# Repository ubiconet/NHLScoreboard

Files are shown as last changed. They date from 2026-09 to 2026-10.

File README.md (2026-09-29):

# NHLScoreboard

ESP32-S3 firmware for a mini NHL scoreboard — a port of the
[MLBScoreboard](https://github.com/ubiconet/mlb_scoreboard) template (same
hardware and framework; the sport layer now lives at `src/sports/nhl/` under
NHL naming). The data layer still speaks the template's MLB feeds; the NHL
rewrite against the documented NHL web API (`docs/features/nhl-api/`) is
the next step.

Hardware (full topology + pin map: [`docs/hardware.md`](docs/hardware.md);
assembly guide + wiring diagram + tables:
[`docs/assembly.md`](docs/assembly.md)):
2.0" ST7789 TFT (320×240) for game details, 3× MAX7219 8×8 matrices (home
score, guest score, period), a TM1637 4-digit period clock, a MAX98357 I2S
audio amp for the goal horn, and 4 penalty LEDs (2 home, 2 guest). Live
linescore for your preferred teams, upcoming-game countdowns, a league news
ticker, an over-the-air captive-portal setup page, and GitHub-hosted
firmware self-update.

The repo is also a **sport scoreboard template**: the generic framework
(`src/common/` + `src/main.cpp`) is sport-agnostic, and everything NHL
lives in `src/sports/nhl/`. See *Starting a new sport* below.

## Architecture

```
┌─────────────────────────── core 1 (Arduino loop) ──────────────────────┐
│ main.cpp (generic shell)      sports/nhl/nhl_app.cpp + renderers       │
│  boot / OTA screen /          WAITING↔LIVE state machine,             │
│  boot status / NTP sync  ──▶  linescore, carousel, news ticker        │
│                               │ takes POD snapshots                   │
└───────────────────────────────┼────────────────────────────────────────┘
                                │ SnapshotChannel<T> (lock-free, gen ctr)
┌────────────────────────── core 0 (FreeRTOS) ───────────────────────────┐
│ network_service (Wi-Fi AP/portal, P2)   nhl_data_task (feeds, P1)     │
│ ota_update (self-update via TLS)         nhl_client → http_fetch      │
└────────────────────────────────────────────────────────────────────────┘
```

Source layout and conventions: see `AGENTS.md` §1. Build/deploy: `AGENTS.md`
§2. Released binaries + `manifest.json` live in [`releases/`](releases/) —
devices self-update from them after boot.

## Building

```powershell
& 'C:\Users\Steve\.platformio\penv\Scripts\platformio.exe' run --environment esp32-s3-devkitc-1
```

Hardware notes (pins, the software-SPI gotcha, heap/TLS constraints) are in
`docs/` and `AGENTS.md`. The verified NHL API reference (endpoints, payload
sizes, TLS constraints) lives in
[`docs/features/nhl-api/README.md`](docs/features/nhl-api/README.md).

## Starting a new sport from this template

The framework (`src/main.cpp` + `src/common/`) never names a sport. A sport
is a folder under `src/sports/` that implements the `sport::` contract
(`src/common/app/sport_api.h`) and provides `sport_config.h`. Checklist:

1. **Copy the repo** (new GitHub repo per sport keeps OTA streams separate).
2. **Copy `src/sports/nhl` → `src/sports/<sport>`** and rewrite the sport:
   - `sport_config.h` — pins/panel geometry, branding (AP SSID, hostname,
     portal title), UI theme colors, feed poll cadences.
   - `nhl_teams.*` — the league's team table `{id, abbrev, label}`.
   - `nhl_snapshot.h` — your live-game POD structs (the MLB template's
     carries balls/strikes/outs and base runners; hockey carries period,
     shots, power play…).
   - `nhl_client.*` — feed endpoints + JSON filters (build on
     `common/comms/http_fetcher`; keep payloads small and check the
     league's transport — the NHL API is HTTPS-only, see
     `docs/features/nhl-api/README.md`).
   - `nhl_data_task.cpp` — poll cadence + parse-to-snapshot publishing.
     **Keep the OTA wiring**: the loop must call
     `serviceOtaUpdates(onlineFor)` every pass, hold feeds while
     `otaUpdateInProgress()`, and gate the first feed fetch behind
     `otaBootGateReached()` — the NHL port dropped these calls once and
     the GitHub self-updater was silently dead until v3.19.
   - `nhl_app.cpp` / renderer files — your screens and state machine.
   - `team_logos.h` / `boot_logo.h` — regenerate assets
     (`tools/gen_boot_logo.py` pattern: RGB565, 0x1909 transparent).
3. **Point the env at it** in `platformio.ini`: change `+<sports/nhl/>`
   to `+<sports/<sport>/>` in `build_src_filter` and `-Isrc/sports/nhl`
   to `-Isrc/sports/<sport>` in `build_flags`, then delete the old folder.
4. **Repo identity**: set `OTA_MANIFEST_URL` / `OTA_LATEST_BIN_URL` in
   `src/config.h`, and `RAW_BASE` + `LATEST_FILE` in
   `tools/release_deploy.py`, to the new repo; bump `FIRMWARE_VERSION` to
   `v1.0`.
5. Build, USB-flash, walk through the setup portal, and run a live-game
   session against your feed.

Notes for the port: NVS keys (`ssid`, `team1..3`, `show_clock`) are shared
by design so a re-purposed board keeps its Wi-Fi; team ids are league-local,
so clear/re-pick teams in the portal after re-flashing a board.

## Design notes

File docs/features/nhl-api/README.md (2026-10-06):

# NHL API — primary data source (verified reference)

The NHL publishes **no official API documentation**. What follows was verified
live against production endpoints on **2026-09-24** (preseason week of the
2026-27 season). The NHL runs two public, unauthenticated surfaces:

| Surface | Base URL | Role for this project |
|---|---|---|
| **Web API** (powers nhl.com) | `https://api-web.nhle.com/v1/` | **Primary**: schedule, live scores, game detail, standings |
| **Stats REST** | `https://api.nhle.com/stats/rest/en/…` | Secondary: team directory (source for the team table) |

Community references (kept up to date by reverse engineering):
<https://github.com/dword4/nhlapi> and the unofficial NHL API reference
mirrors linked from it. The old `statsapi.web.nhl.com/api/v1` API is **dead**
(dark since ~2023); any guide referencing it is out of date.

## Transport properties (all verified)

- **HTTPS only.** `http://` answers `301` (Cloudflare) to the `https://` URL.
  This is a major departure from the MLB template, which ran feeds over plain
  HTTP and reserved TLS for OTA only — see *ESP32 constraints* below.
- **No authentication**, no API key, no required headers (works with a bare
  `curl` User-Agent).
- **No response filtering.** Unlike MLB's `?fields=` parameter there is no way
  to slim a payload server-side; sizes below are full bodies.
- HTTP/1.1 **keep-alive** works; served via Cloudflare with
  `Cache-Control: max-age=14` and a weak ETag — polling a live endpoint faster
  than ~15 s mostly hits CDN cache.
- Localized string fields are objects: `{"default": "Penguins", "fr": …}` —
  always read the `default` sub-key.
- `/v1/*/now` endpoints answer **307 redirects** to the current date. On the
  device, compute the date locally from the NTP-synced clock instead of
  following redirects (a redirect doubles the TLS round trips).

## Game identity & state

- **Game id** (e.g. `2026010016`): `YYYY` + 2-digit `gameType` + 4-digit
  sequence. `gameType`: `1` preseason, `2` regular season, `3` playoffs.
  The `season` field is the two years joined: `20262027`.
- **`gameState`** (observed: `FUT`, `FINAL`, `OFF`; community also documents
  `PREVIEW`, `LIVE`, `CRIT`):
  - `FUT` — scheduled, future
  - `PREVIEW` — game day, before start
  - `LIVE` — in progress
  - `CRIT` — critical/late (final minutes, OT)
  - `FINAL` / `OFF` — completed (`OFF` = official/finalized)
- **`periodDescriptor`**: `{"number": 3, "periodType": "REG", "maxRegulationPeriods": 3}`
  — `periodType` is `REG`, `OT`, or `SO` (shootout).

## Endpoints

### `GET /v1/score/{yyyy-mm-dd}` — day scoreboard *(waiting-mode poll)*

~42 KB. Top-level: `prevDate`, `currentDate`, `nextDate`, `gameWeek[]`
(per-day `date`/`dayAbbrev`/`numberOfGames` metadata only), `games[]`.

Each game carries the live essentials in one flat array (this is the smallest
"everything happening today" payload):

```json
{"id": 2026010016, "season": 20262027, "gameType": 1,
 "gameDate": "2026-09-21", "startTimeUTC": "2026-09-21T23:00:00Z",
 "gameState": "FINAL", "gameScheduleState": "OK",
 "clock": {"timeRemaining": "00:00", "secondsRemaining": 0,
           "running": false, "inIntermission": false},
 "period": 3, "periodDescriptor": {"number": 3, "periodType": "REG",
                                   "maxRegulationPeriods": 3},
 "gameOutcome": {"lastPeriodType": "REG"},
 "awayTeam": {"id": 7, "name": {"default": "Sabres"}, "abbrev": "BUF",
              "score": 1, "sog": 24,
              "logo": "https://assets.nhle.com/logos/nhl/svg/BUF_light.svg"},
 "homeTeam": {"id": 5, "name": {"default": "Penguins"}, "abbrev": "PIT",
              "score": 4, "sog": 28, "logo": "..."},
 "goals": [ … ], "tvBroadcasts": [ … ], "venue": {"default": "PPG Paints Arena"},
 "gameCenterLink": "/gamecenter/pit-vs-buf/2026/09/21/2026010016"}
```

One request covers every game of the day — the analog of the MLB template's
single schedule fetch.

### `GET /v1/schedule/{yyyy-mm-dd}` — week schedule *(schedule cache / countdown)*

~85 KB. Returns the **Mon–Sun week containing the date**, plus:
`nextStartDate` / `previousStartDate` (for paging), `numberOfGames`, and the
season boundaries `preSeasonStartDate`, `regularSeasonStartDate`,
`regularSeasonEndDate`, `playoffEndDate` (useful for "is today in season").

Game objects here add vs. `/v1/score`: `commonName`/`placeName` (split team
names), `darkLogo`, `winningGoalie`, `winningGoalScorer`, `threeMinRecap`,
`condensedGame`, `oddsPartners`.

### `GET /v1/gamecenter/{id}/landing` — live game summary *(live-screen poll)*

~11 KB. **The NHL analog of MLB's `/linescore`** — poll this while a followed
game is live:

```json
{"id": 2025020001, "gameState": "OFF",
 "periodDescriptor": {"number": 3, "periodType": "REG"},
 "clock": {"timeRemaining": "00:00", "secondsRemaining": 0,
           "running": false, "inIntermission": false},
 "shootoutInUse": false, "otInUse": true, "tiesInUse": false,
 "maxPeriods": 5, "regPeriods": 3,
 "homeTeam": {"abbrev": "FLA", "score": 3, "sog": 37, …},
 "awayTeam": {"abbrev": "CHI", "score": 2, "sog": 19, …},
 "summary": {
   "scoring": [
     {"periodDescriptor": {"number": 1}, "goals": [
        {"strength": "ev", "playerId": 8483493, "name": {"default": "F. Nazar"},
         "teamAbbrev": {"default": "CHI"}, "situationCode": "1551",
         "highlightClipSharingUrl": "https://nhl.com/vid…"}]},
     … one entry per period with goals …],
   "threeStars": [ {"star": 1, "name": {"default": "…"}, "teamAbbrev": "FLA",
                    "goals": 1, "assists": 0, "points": 1} ],
   "penalties": [ {"periodDescriptor": {"number": 1}, "penalties": [
        {"timeInPeriod": "06:58", "duration": 2, "descKey": "slashing",
         "teamAbbrev": {"default": "CHI"}}]}]}}
```

A period-by-period **linescore is derived** from `summary.scoring[]` (count
`goals[]` per `teamAbbrev` per period). Shots on goal per period are **not**
exposed here — only game totals (`sog`); per-period shots must be aggregated
from play-by-play if a screen ever needs them.

The live scoreboard also filters each scoring entry's scorer and assist
names, IDs, and sweater numbers from this summary. If the scorer's sweater
number is absent, it makes a one-time, roster-only filtered
`/v1/gamecenter/{id}/play-by-play` request when the score first increases;
the large play/event list is not retained or fetched on routine polls.
The same pass counts goals per `teamAbbrev` per period group (the group's
`periodDescriptor` is part of the filter) to build the per-period
linescore strip, and `summary.threeStars[]` (name, sweater number, team,
G/A) feeds the postgame three-stars screen — that array is only populated
at or near game end.

`situationCode` encodes strength as four digits —
`[awayGoalies][awaySkaters][homeSkaters][homeGoalies]`, e.g. `"1551"` = 5v5
with both goalies, `"0651"` = away team on an empty-net extra attacker. This
is the natural source for a **power-play indicator** (replacing MLB's
balls/strikes/outs LEDs — actual LED meaning is a board-topology decision,
out of scope here).

### `GET /v1/gamecenter/{id}/boxscore` — box score

~13.5 KB. Same envelope (`gameState`, `clock`, `periodDescriptor`, teams with
`score` + `sog`) plus `playerByGameStats: {homeTeam/awayTeam:
{forwards, defense, goalies}}` (per-player G/A/TOI/SOG…) and `gameOutcome`.
Use for a stats screen; **not** needed for the live poll.

### `GET /v1/gamecenter/{id}/play-by-play` — full event stream

~146 KB for a completed regular-season game. `plays[]` (361 events in the
sample): `eventId`, `periodDescriptor`, `timeInPeriod`, `timeRemaining`,
`situationCode`, `typeCode`/`typeDescKey` (`period-start`, `faceoff`,
`shot-on-goal`, `goal`, `stoppage`, `game-end`, …), event `details` (players,
zone, coordinates), `sortOrder`; plus `rosterSpots` and a `summary`.
The last `plays[]` entry is the "current play" analog of MLB's live feed.

Too large for the render path and marginal for the ESP32 parse budget —
reserve for an on-demand drill-down screen, parsed on core 0 with a streaming
filter (see constraints).

### `GET /v1/standings/{yyyy-mm-dd}` — standings

~60 KB. `/v1/standings/now` 307-redirects to the latest date with standings —
during the 2026 preseason that was **2026-04-17** (end of the previous
season), which is the right behavior for an offseason carousel. Entries
include `divisionAbbrev`/`conferenceAbbrev` + rank sequences,
`wildCardIndicator`, `clinchIndicator`, `gamesPlayed`, `points`, `pointPctg`,
`goalDifferential`, L10/home/road splits.

### `GET https://api.nhle.com/stats/rest/en/team` — team directory

~6.7 KB: `{"data": [{"id": 32, "franchiseId": 27, "fullName": "Quebec
Nordiques", "leagueId": 133, "rawTricode": "QUE", "triCode": "QUE"}, …]}`.
**Includes defunct franchises** — filter to the 32 active clubs when
generating the hardcoded `nhl_teams.*` table (`{id, abbrev, label}`). Supports
`cayenne_exp` filter expressions (community-documented); the scoreboard
itself never needs them.

### Team logos & player assets

Embedded in schedule/score payloads:
- `https://assets.nhle.com/logos/nhl/svg/{ABBREV}_light.svg`
- `https://assets.nhle.com/logos/nhl/svg/{ABBREV}_dark.svg`
  (some carry `?season=YYYYYYYY`)
- Player headshots: `https://assets.nhle.com/mugs/nhl/{season}/{ABBREV}/{playerId}.png`

### News

**No accessible official NHL endpoint**: `/v1/news` → 404, and
`https://www.nhl.com/rss/news.xml` → 403 (Akamai bot filter — would likely
block the ESP32 too). Chosen source (live since v1.8): **ESPN's NHL feed on
`site.api.espn.com`** over plain HTTP —
`http://site.api.espn.com/apis/site/v2/sports/hockey/nhl/news?limit=10`
(~27 KB with limit=5; `articles[].headline`/`description` are all the
ticker parses, via a streaming filter). ESPN's `www.espn.com/espn/rss/nhl/news`
RSS carries the same stories at 9 KB but **301-forces HTTPS**, which the
TLS-free feed architecture (see `common/comms/http_fetcher.h`) avoids; the
api host serves plain HTTP with no redirect and tolerated an ESP32
User-Agent in testing. Keep the ≥30-min cache rule and the gentle retry
pacing (`NHL_NEWS_RETRY_MS`) — ESPN's edge has a temper.

## MLB template → NHL mapping (porting cheat sheet)

| MLB template | NHL equivalent |
|---|---|
| `gamePk` | `id` (`2026010016`) |
| `/api/v1/schedule?sportId=1&date=` | `/v1/score/{date}` (day, 42 KB) or `/v1/schedule/{date}` (week, 85 KB) |
| `/game/{pk}/linescore` | `/v1/gamecenter/{id}/landing` (11 KB) |
| `/game/{pk}/boxscore` | `/v1/gamecenter/{id}/boxscore` (13.5 KB) |
| `/v1.1/game/{pk}/feed/live` | `/v1/gamecenter/{id}/play-by-play` (146 KB) |
| `/api/v1/standings` | `/v1/standings/{date}` |
| `detailedState` (PreGame/InPlay/Over) | `gameState` (PREVIEW/LIVE·CRIT/FINAL·OFF) |
| inning / half inning | `periodDescriptor.number` + `periodType` (REG/OT/SO) |
| inning-by-inning runs | derive from `landing.summary.scoring[]` |
| at-bat | last `plays[]` entry / `situationCode` strength |
| balls/strikes/outs | power-play/strength indicator (board topology TBD) |
| `team.id` / `abbrev` / name | `id` / `abbrev` / `placeName` + `commonName` |
| W-L record in standings | `points`, `pointPctg`, wildcard flags |
| ESPN `mlb` news | ESPN `hockey/nhl` news |

## ESP32 constraints (architecture notes for the rewrite)

- **Everything is TLS now.** The MLB template ran feeds on plain HTTP with a
  single reused TLS session reserved for OTA. With NHL feeds, every fetch is
  TLS: plan on one reused `WiFiClientSecure` connection per poll cycle on
  core 0, never concurrent sessions (the OTA rule "no second TLS connection
  while one is alive" still applies and now interacts with feed polling —
  the feed session must close before the OTA updater runs, as the template
  already does via `http_fetch::closeSession()`).
- **Payload budget.** `score` (42 KB), `landing` (11 KB) and `boxscore`
  (13.5 KB) fit the template's buffered-parse discipline. `schedule` week
  (85 KB), `standings` (60 KB) and especially `play-by-play` (146 KB) must
  be fetched sparsely (schedule cache / carousel TTL) or parsed with a
  streaming filter on core 0 — never parsed on the render core.
- **No `fields=` filtering** — filter in the parser.
- **CDN freshness is 14 s** — a 15–20 s live cadence is the fastest useful
  poll; faster requests just hit Cloudflare cache.
- **Avoid `/now`** — compute dates locally (NTP) rather than following 307s.
- Localized fields are objects — always read `.default`.

## Samples (captured 2026-09-24)

| File | Endpoint | Size |
|---|---|---|
| `samples/score-2026-09-21.json` | `/v1/score/2026-09-21` | 42 KB |
| `samples/schedule-2026-09-21.json` | `/v1/schedule/2026-09-21` | 85 KB |
| `samples/landing-2025020001.json` | `/v1/gamecenter/2025020001/landing` | 11 KB |
| `samples/boxscore-2025020001.json` | `/v1/gamecenter/2025020001/boxscore` | 13.5 KB |
| `samples/play-by-play-2025020001.json` | `/v1/gamecenter/2025020001/play-by-play` | 146 KB |

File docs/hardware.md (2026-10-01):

# Hardware — NHL board topology & physical pin map

The NHL build's outputs, their drivers, and the GPIO plan mapped to the
**physical header positions** of the actual dev board (the logical GPIO
numbers are NOT in order on its headers, so assignments below are chosen
for physical sequence). **v3.44 moved the TFT and the guest penalty LEDs
to the backplane-PCB routing** (`pcb.md`) — the dev-board headers below
are now intermediate, but the GPIO↔position map is still the board's
truth. Since v2.0 the firmware drives this target map for the TM1637,
penalty LEDs, and the MAX7219 chain; the remaining topography items are
the third (period) MAX7219 module — the `led_matrix` HAL still drives
two — and the MAX98357 I2S audio output.

For building the physical board see **[`assembly.md`](assembly.md)** —
parts list, wiring tables, the rendered wiring diagram
(`wiring-diagram.png`), and the first-boot checklist.

## Board

ESP32-S3 DevKit ("esp32s1-devkit1", a YD-ESP32-S3-family 44-pin DevKitC-1
clone), **ESP32-S3-WROOM-1 N8R8** (8 MB quad flash + 8 MB octal PSRAM).
Two USB-C ports at the bottom edge: the **native USB OTG** port (GPIO
19/20 — use this one for `Serial`/CDC and flashing) and a **USB-UART
bridge** port (CH343 → GPIO 43/44). RST + BOOT buttons on the side, and an
onboard WS2812 RGB LED on **GPIO48** (don't use 48 for I/O). On some YD
boards the `USB-OTG` solder jumper ships open — close it if the native USB
port is dead. Both headers below are confirmed against the board (note:
position 7 on the right is GPIO41 — easy to misread as 21, but 21 sits at
position 18 and a GPIO can't appear twice).

## Outputs

| # | Output | Part | Role | Interface | GPIOs |
|---|---|---|---|---|---|
| 1 | Home score | MAX7219 8×8 matrix | Home goals | chained SPI | 40/39/38 |
| 2 | Guest score | MAX7219 8×8 matrix | Guest goals | chained SPI | (same chain) |
| 3 | Period | MAX7219 8×8 matrix | 1–4, OT, SO | chained SPI | (same chain) |
| 4 | Period clock | TM1637 4-digit 7-seg | MM:SS game clock | 2-wire bit-bang | 16/17 |
| 5 | Audio | MAX98357 I2S amp + speaker | goal horn / cues | I2S | 1/2/42 |
| 6 | Home penalties | 2 discrete LEDs | penalty 1 / penalty 2 | GPIO direct | 4/5 |
| 7 | Guest penalties | 2 discrete LEDs | penalty 1 / penalty 2 | GPIO direct | 11/12 |
| 8 | Game details | 2.0" ST7789 240×320 TFT | linescore, carousel, portal | software SPI | 8/3/9/10/46 |

**Total: 17 GPIOs.** Wiring-friendly split: **left header = indicators +
displays**, **right header = serial buses** (audio + score matrices).

## Physical header map

### LEFT header (top → bottom, confirmed)

| Pos | Pin | Assigned to | Note |
|---|---|---|---|
| 1 | 3V3 | — | power for TM1637 |
| 2 | 3V3 | — | power for TFT |
| 3 | RST | — | |
| 4 | GPIO4 | Home penalty LED 1 | |
| 5 | GPIO5 | Home penalty LED 2 | |
| 6 | GPIO6 | — spare — | guest LED until the PCB rev (v3.44) |
| 7 | GPIO7 | — spare — | guest LED until the PCB rev (v3.44) |
| 8 | GPIO15 | — gap — | spare |
| 9 | GPIO16 | TM1637 CLK | |
| 10 | GPIO17 | TM1637 DIO | |
| 11 | GPIO18 | — gap — | spare |
| 12 | GPIO8 | TFT SCL (SCK) | PCB rev v3.44 |
| 13 | GPIO3 | TFT SDA (MOSI) | strapping pin (JTAG source) — output OK after boot |
| 14 | GPIO46 | TFT RESET | strapping pin — output OK after boot; reset state only gates ROM log |
| 15 | GPIO9 | TFT DC | |
| 16 | GPIO10 | TFT CS | |
| 17 | GPIO11 | Guest penalty LED 1 | |
| 18 | GPIO12 | Guest penalty LED 2 | |
| 19 | GPIO13 | — spare — | PENALTY_FILL_A dummy (init'd, never lit) |
| 20 | GPIO14 | — gap — | spare |
| 21 | 5V | — | power for MAX7219 chain + MAX98357 |
| 22 | GND | — | |

### RIGHT header (top → bottom, confirmed)

| Pos | Pin | Assigned to | Note |
|---|---|---|---|
| 1 | GND | — | ground for I2S/matrices |
| 2 | TX (43) | — | UART debug spare |
| 3 | RX (44) | — | UART debug spare |
| 4 | GPIO1 | MAX98357 BCLK | |
| 5 | GPIO2 | MAX98357 LRC (WS) | |
| 6 | GPIO42 | MAX98357 DIN (data) | |
| 7 | GPIO41 | — gap — | spare (JTAG MTDO) |
| 8 | GPIO40 | MAX7219 DIN (chain in) | |
| 9 | GPIO39 | MAX7219 CLK | |
| 10 | GPIO38 | MAX7219 CS / LOAD | |
| 11 | GPIO37 | ✗ | octal PSRAM (N8R8) |
| 12 | GPIO36 | ✗ | octal PSRAM (N8R8) |
| 13 | GPIO35 | ✗ | octal PSRAM (N8R8) |
| 14 | GPIO0 | ✗ | strap / boot button |
| 15 | GPIO45 | ✗ | strapping pin |
| 16 | GPIO48 | ✗ | onboard RGB LED |
| 17 | GPIO47 | — spare — | expansion |
| 18 | GPIO21 | — spare — | expansion |
| 19 | GPIO20 | ✗ | native USB D+ |
| 20 | GPIO19 | ✗ | native USB D− |
| 21 | GND | — | |
| 22 | GND | — | |

## Design rationale

1. **Physical sequence per device.** Each peripheral occupies consecutive
   header positions: LEDs 4–7, TM1637 9–10, TFT 15–19 (left); I2S 4–6,
   MAX7219 chain 8–10 (right). One-position gaps (left 8, 11, 20; right 7)
   separate devices visually and electrically.
2. **Minimal pins.** The three MAX7219 matrices share one 3-pin daisy
   chain (CLK + CS common, data cascades DOUT→DIN), so the Period matrix
   costs zero extra pins. TM1637 is 2 pins, MAX98357 is 3 (I2S), penalty
   LEDs are 4.
3. **PCB routing wins (v3.44).** The original map put the TFT on the
   MLB-proven `CS=9, DC=10, RESET=11, MOSI=12, SCK=13` run (left 15–19)
   and the guest LEDs on 6/7; the backplane PCB's routing moved the TFT to
   `SCK=8, MOSI=3, CS=10, DC=9, RESET=46` and the guest LEDs to 11/12.
   GPIO 3 and 46 are strapping pins, but both are TFT inputs on the module
   side, so the strap sample at reset is undisturbed and both work fine
   as outputs once firmware drives them.
4. **Avoided by design:** GPIO 35–37 (octal PSRAM on N8R8), 0/45
   (straps), 48 (onboard RGB), 19/20 (native USB), 43/44 (debug UART).
   46 (strap) is now the TFT reset — tolerated because its reset-time
   state only gates ROM log output. When adding parts prefer GPIO 15/18/14
   (left) or 41/47/21 (right).

## Wiring notes

**MAX7219 chain** — data flows GPIO 40 → matrix 1 (Guest) DIN → DOUT →
matrix 2 (Period) DIN → DOUT → matrix 3 (Home) DIN. CLK and CS/LOAD are
shared by all three. With a shared LOAD the first bytes shifted land in
the **last** physical device (home) — the driver's `max7219Send3` orders
its slots accordingly.

**TM1637** — power from 3V3 (left pos 1/2): its input high threshold
scales with VCC, so 5 V power makes 3.3 V logic marginal. Slightly dimmer
at 3V3 but 100 % reliable.

**MAX98357** — Vin from 5V; logic inputs are 3.3 V safe. Leave SD
unconnected (default: active, 9 dB gain). Speaker 4 Ω/3 W or 8 Ω.

**Penalty LEDs** — GPIO → LED → 330–470 Ω → GND.

**Common ground** — everything shares the board GND (corners + right pos
1/19); the I2S and bit-banged SPI signals are unforgiving of ground
bounce.

## Flash / partitions (N8R8)

8 MB flash: `partitions.csv` gives the OTA app slots 3.375 MB each (the
image uses ~42%). PSRAM (8 MB octal) is NOT enabled in firmware yet —
`board_build.arduino.memory_type = qio_opi` is already set, so enabling it
later is just `-DBOARD_HAS_PSRAM`. First use: parse the big NHL payloads
(week schedule 85 KB, play-by-play 146 KB) into PSRAM instead of internal
RAM, keeping the TLS-context heap intact.

## Driver notes (for the topography rewrite)

- **TM1637** — bit-banged 2-wire driver; render MM:SS from the live
  snapshot clock fields.
- **MAX98357** — ESP32-S3 I2S TX (16-bit mono is enough), PCM clips in
  PROGMEM, DMA playback triggered from **core 0**; nothing blocking in
  `sport::tick()`.
- **Matrices** — extend `common/hal/led_matrix` to 3 devices (24 bits per
  update, one LOAD pulse); map chain positions to Home/Guest/Period
  honoring the last-device-first-shifted ordering.
- **Penalty LEDs** — reuse `common/hal/count_leds` with a 4-pin table.
- TFT rendering, dirty-rect discipline, and the core split are unchanged.

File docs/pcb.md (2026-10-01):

# NHLScoreboard — backplane PCB design (CNC starting point)

A single-sided carrier board that replaces the point-to-point wiring: the
DevKit-1 plugs on, every module connects by header, the penalty LEDs and
resistors are surface-mounted, and one 5 V feed powers everything. Sized
to sit behind the 3D-printed front panel (model: `NHL Scoreboard.stl`,
220 × 114 mm). Reference drawing: `pcb-layout.svg` (1:1 front view,
regenerate with `tools/gen_pcb.py`).

## Layout read from the 3D model (front view, mm, origin at board center)

| Zone | Position (x, y) | Size | Notes |
|---|---|---|---|
| Board | (0, 0) | 220 × 114 | matches panel |
| Matrix cutout LEFT | (−68, −12) | 32 × 32 | full-module cutout |
| Matrix cutout RIGHT | (68, −12) | 32 × 32 | full-module cutout |
| Matrix PERIOD window | (23, −20.5) | 20 × 20 | below/right of the clock — LED face window, 32×32 module sits behind |
| TM1637 | (0, −45.8) | 31 × 15 | top center |
| DevKit-1 | (0, 6) | 70 × 53 | centered |
| TFT 2.0" | (0, 15) | 48 × 38 | center, below DevKit top zone |
| Mounting holes 4 × Ø5 | (±63.9, 28.5), (±73.4, 28.5) | — | panel standoffs |
| Label text band | y ≈ −34..−55 | — | raised text across top |
| Label under each matrix | y ≈ 16..22 | 31 × 6 | e.g. HOME / GUEST |

The MAX98357 amp needs no panel cutout (audio only) — it lives on the
backplane in the free lower-right area, near the speaker terminal.

## Connectors and parts (all on the back of the PCB, copper milled on the
same single side; modules face the panel through their cutouts)

| Ref | Part | Position | Pins / nets |
|---|---|---|---|
| J1 | 2 × 20-pin female header (DevKit socket) | (0, 6) zone | see pin map |
| J2 | 1 × 7 female header (TFT) | (0, −2) | VCC GND SCL SDA RES DC CS |
| J3 | 1 × 4 (TM1637) | (0, −45.8) | VCC GND CLK DIO |
| J4 | 1 × 5 (matrix 1 = GUEST) | (−68, 8) | VCC GND DIN CLK CS |
| J5 | 1 × 5 (matrix 2 = PERIOD) | (23, −20.5) | behind its 20×20 window |
| J6 | 1 × 5 (matrix 3 = HOME) | (68, 8) | VCC GND DIN CLK CS |
| J7 | 1 × 5 (MAX98357) | (66, 40) | VIN GND BCLK LRC DIN |
| J8 | 1 × 2 (speaker) | (84, 40) | — |
| J9 | 1 × 2 screw terminal 5.08 (5 V in) | (0, 48) | 5V GND |
| D1–D4 | SMD LED 1206 + label side | (−90, −44) (−45, −44) (45, −44) (90, −44) | H1 H2 G1 G2 |
| R1–R4 | **220 kΩ** 0805 | beside each LED | series with LED — see note |
| C1–C6 | 100 nF + 10 µF 0805/1206 per matrix header | at J4–J6 | local decoupling |

> **LED resistor note**: at 3.3 V a 220 kΩ series resistor limits the LED
> to ~15 µA — effectively dark on standard LEDs. If the intent was the
> classic 220 **Ω** (≈13 mA, bright), change the value in
> `tools/gen_pcb.py` and this table. High-efficiency LEDs that genuinely
> run at 220 kΩ exist; verify with a bench test before milling.

## Rough trace plan (drawn in `pcb-layout.svg`)

- **Shared GND rail** (black, 2 mm): a perimeter ring inset 3 mm from the
  board edge, with taps dropping/rising to every connector's GND, the
  LED cathodes, and the DevKit. The ring keeps every return short and
  gives the matrix current a wide path home.
- **Shared 5V rail** (red, 2 mm): from J9 the rail splits left and right
  along the bottom edge, rising to J4 (left matrix) and J6 (right
  matrix), with branches to J7 (amp) and a routed run up the right of
  the DevKit zone to J5 (period matrix) and the DevKit's 5V pin.
- **Signals** (colored, 0.9 mm): the TFT bundle drops straight from J2
  into the DevKit's top row; TM1637 wraps the DevKit's left; the matrix
  CLK/CS bus rides a corridor at y ≈ −32..−35 above the DevKit to reach
  all three matrix headers; GPIO 40's DIN and the two dashed chain
  jumpers (J4→J5→J6) route below/around the DevKit; I2S runs down the
  right side to the amp; the four LED drives fan up to the top band.
- Dashed teal = the DOUT→DIN jumpers, which can be traces OR short
  wires if the milling gets tight.

Positions are a starting point — shift the small parts freely; keep J1's
zone exactly on the DevKit footprint.

## DevKit socket footprint (J1)

The controller measures **56 × 28 mm** (compact S3 dev board — not the
larger DevKitC). Socket: two rows of female header along the 56 mm edges,
pads at 2.54 mm pitch spanning ~48.3 mm, row spacing ~24.1 mm — **measure
your board's row spacing and pad count before drilling** (compact boards
run 19–20 pads per row). Only the used pins below need copper; the rest
of the pads may go unrouted.

### Pin map — only the used pins need copper

| Signal | DevKit pin | Goes to |
|---|---|---|
| 3V3 (two pins) | rail | J2 VCC, J3 VCC |
| 5V | rail | J9-1, J4/J5/J6 VCC, J7 VIN |
| GND (4 pins) | rail | everything (star at J9-2) |
| GPIO 8/3/46/9/10 | TFT | J2 SCL/SDA/RES/DC/CS |
| GPIO 16/17 | TM1637 | J3 CLK/DIO |
| GPIO 40/39/38 | matrices | J4 DIN, CLK bus (39), CS bus (38) |
| GPIO 1/2/42 | I2S | J7 BCLK/LRC/DIN |
| GPIO 4/5/11/12 | LEDs | R1/R2/R3/R4 (H1 H2 G1 G2) |

Matrix daisy-chain ON the PCB: J4 DOUT pad → J5 DIN, J5 DOUT → J6 DIN
(short jumpers on the copper side; label them on the silk).

## Netlist summary

- **5V**: J9-1 → DevKit 5V pin → J4/J5/J6 VCC → J7 VIN.
- **3V3**: DevKit 3V3 pins → J2 VCC, J3 VCC. (No regulator on board —
  the DevKit's supplies both rails.)
- **GND**: J9-2 → DevKit GND → all headers, LED cathodes. Keep one star
  point near J9; the matrix returns are the biggest current path.
- **Signals**: straight point-to-point per the pin map above; only the
  three matrix buses (DIN chain, CLK, CS) route to more than one place.

## CNC fabrication rules (single-sided, isolation routing)

- 1 oz copper, FR-1/FR-4; copper on the BACK (components mounted from the
  back so they face the panel through its cutouts).
- V-bit 30–60°, 0.1–0.2 mm tip; isolation ≥ 0.4 mm (16 mil).
- Signal traces ≥ 0.8 mm; 5 V / GND trunk ≥ 2 mm (three matrices can
  pull ~1 A at full brightness).
- Pads ≥ 1.6 mm annular ring; drill 0.9 mm signal, 1.2 mm power/terminal,
  3.2 mm at the four model hole positions (M3 screws through Ø5 panel
  holes).
- No plane fill needed; a fat GND trace ringing the board keeps returns
  short. If your mill is reliable, a hatched ground pour is nicer but
  optional.
- Export path when ready for KiCad: recreate this layout on F.Cu →
  generate Gerber + drill → FlatCAM (or pcbgcode) for isolation toolpaths.

## Build order

1. Mill + drill, deburr, tin or leave bare copper.
2. SMD first: R1–R4, D1–D4 (check polarity against the front labels),
   C1–C6.
3. Headers: J1 female (DevKit plugs in last), J2–J9.
4. Bench test BEFORE plugging the DevKit: continuity-beep every net in the
   pin map, then power J9 from a current-limited 5 V supply and verify
   5 V on J4/J5/J6/J7 VCC and 0 Ω nowhere it shouldn't be.
5. Plug the DevKit, flash the bench test firmware
   (`HARDWARE_TEST_MODE = true`), verify all displays through the
   connectors, then flash production firmware.

---

## CNC fabrication package (fab/) — generated by `tools/gen_pcb_fab.py`

Single source of truth = PADS/TRACES/JUMPERS tables in the script. It emits
into `fab/`: `copper-bottom.gbr` (all copper), `board-outline.gbr`,
`drill.drl` (Excellon: T1 0.9mm signal, T2 3.2mm LED corner holes), and
`preview.svg`. A built-in checker reports cross-net trace crossings —
**current status: 0**. Load the two Gerbers + drill into FlatCAM/bcnc to
generate isolation-milling G-code (0.8mm signal / 1.5mm power / 2mm GND ring,
>=0.3mm isolation; cut on the BOTTOM side as drawn — mirror in your CAM if
you prefer viewing from the top).

Frame = panel SVG coords exactly: x ±110, y −66 (top) .. +48 (bottom).
Component pin orders verified from photos in `docs/components/`
(tft.jpg, scorematrix.jpg, periodmatrix.jpg, audioamp.jpg):
TFT GND-VCC-SCL-SDA-RST-DC-CS · matrices VCC-GND-CS-CLK-DIN(-DOUT) ·
amp LRC-BCLK-DIN-GAIN-SD-GND-Vin · TM1637 CLK-DIO-VCC-GND.

**Penalty LEDs are 5mm THT centered in the four panel round holes**
(±63.9/±73.4, y 28.5) with 220k SMD-1206 series resistors inline (R1–R4).
J6 (home matrix) is plugged rotated 180° so VCC is the bottom pin.

### 13 assembly wires (dashed yellow in preview.svg)
The MAX7219 chain also needs module-to-module wiring — modules daisy-chain
through their own pass-through headers, so wire J4 DOUT→J5 DIN and
J5 DOUT→J6 DIN with dupont jumpers; CLK/CS/5V/GND tap from J4's spare pins.

1. 5V right feed: (8,41) → (98,−16) [feeds J6 VCC + J7 Vin]
2. 5V J4 feed: (−29.5,−2) → (−74,−16)
3. TFT VCC: J2 VCC pin → DevKit 3V3 pin
4. TFT GND: J2 GND pin → (22.5,−42)
5. TM1637 GND: (22.5,−42) → J3 GND pin
6. TM1637 CLK/DIO: J3 pins → DevKit 16/17 pins (2 wires)
7. Away LEDs ×2, Home LEDs ×2: resistor pads (56/70, ±24) → (−28,−19/−21)
8. J4 CS wire: (−92,−15) → J4 CS pin (continue to J5/J6 CS)
9. J4 CLK wire: (−87,−12) → J4 CLK pin

### Firmware pin changes — final routing (applied in v3.44)
- TFT: SCK 13→8, MOSI 12→3, RESET 11→46, CS 9→10, DC 10→9
- Penalty LEDs: GUEST1 6→11, GUEST2 7→12 (home stay 4/5)
- PENALTY_FILL_A 8→13 (GPIO 8 became the TFT SCL — `initCountLeds`
  configures the fill pins, so it can no longer sit there)
- The first routing's proposals (I2S to BCLK=43/LRC=44/DIN=1, home LED
  4↔5 swap) were superseded by the final routing — I2S stays
  BCLK=1, LRC=2, DIN=42; home LEDs stay 4/5.

**Verify against hardware before cutting** (per your note): header
positions/orientations, J6 rotation, LED hole alignment, DevKit placement
(rows x ±24.13, pads y −24.67..28.67).

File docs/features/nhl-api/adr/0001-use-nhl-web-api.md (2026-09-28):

# ADR-0001 — Use the NHL public web API as the primary data source

- **Status**: Accepted (supersedes the MLB-template ADR of the same number)
- **Date**: 2026-09-24

## Context

NHLScoreboard needs live NHL scores, schedules, boxscores, and standings.
Candidate sources:

1. **NHL public web API** (`https://api-web.nhle.com/v1/`, free,
   unauthenticated, undocumented — the same endpoints nhl.com itself uses).
   Plus the stats REST surface (`https://api.nhle.com/stats/rest/en/…`) for
   reference data like the team directory.
2. **Commercial APIs** (Sportradar — the NHL's official data partner,
   SportsData.io): officially documented, SLA-backed, paid licensing.
3. **ESPN hidden API** (`site.api.espn.com`): free and convenient, but a
   third-party dependency for the league's own data.
4. **Community scrapers/libraries**: wrap the same endpoints; add a
   dependency without adding a data guarantee; no maintained ESP32/C++
   client exists anyway.

## Decision

Use the NHL public web API directly as the primary data source, behind our
own thin data-access layer (`nhl_client.*` on core 0). Use ESPN's
`hockey/nhl` news feed only for the news ticker, where the NHL itself has no
accessible endpoint (verified: `/v1/news` 404, `nhl.com/rss/news.xml` 403
bot-blocked).

## Consequences

**Positive**

- Free, no key management, no contract; covers every scoreboard need
  (day scores, week schedule, live game state, boxscore, standings).
- Same API that powers nhl.com and the official NHL app — well-exercised in
  production even without formal documentation.
- Payloads are compact where it matters for a microcontroller: the day
  scoreboard is 42 KB, the live-game `landing` summary 11 KB.

**Negative / risks & mitigations**

- Undocumented and can change without notice (the league already killed
  `statsapi.web.nhl.com` once). Mitigate with: lenient parsing, contract
  tests against checked-in live samples (`samples/`), configurable base URL,
  and monitoring the community `dword4/nhlapi` documentation for breakage.
- No SLA or rate-limit guarantee: keep request volume conservative and cache.
- **HTTPS-only** (unlike MLB's plain-HTTP feeds): every fetch costs a TLS
  session. The firmware must reuse connections and budget heap accordingly —
  see the constraints section of `docs/features/nhl-api/README.md`.
- No server-side field filtering (`?fields=`): payloads must be trimmed in
  the parser, on core 0.
- **Exit strategy**: swap the data-access layer to Sportradar's NHL API
  (official partner, closest feature match) if reliability becomes
  unacceptable; the rest of the app is insulated behind that layer.

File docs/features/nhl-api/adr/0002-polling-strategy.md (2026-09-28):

# ADR-0002 — Polling cadence driven by game state; no push channel

- **Status**: Accepted (NHL adaptation of the MLB-template ADR)
- **Date**: 2026-09-24

## Context

The NHL web API is request/response HTTP with no published WebSocket/SSE
channel for live scores. The scoreboard must feel live (~30 s staleness
budget) without hammering an undocumented, limit-unknown service — and every
request is a TLS round trip (see ADR-0001), so request count matters more
than in the MLB template. Hockey has natural pauses (intermissions, TV
timeouts, stoppages) but also continuous play, so cadence should track game
state.

A second, NHL-specific constraint: Cloudflare serves the live endpoints with
`Cache-Control: max-age=14`, so polling faster than ~15 s returns cached
bytes anyway.

## Decision

Poll `GET /v1/score/{date}` (one request covers every game that day) and
`GET /v1/gamecenter/{id}/landing` (11 KB, per followed live game) on a
cadence chosen by aggregate game state:

| Aggregate state of the day's games | Cadence |
|---|---|
| No games, or all `FUT` more than 1 h away | 10 min |
| Games within 1 h (`FUT`, `PREVIEW`) | 2 min |
| Any game `LIVE` (period in play or intermission) | 20 s |
| Any game `CRIT` (final minutes / OT / shootout) | 15 s (CDN floor) |
| All games `FINAL`/`OFF` | stop polling (refetch on state change) |

Implementation rules:

- A single scheduler on core 0 owns all polling; the day fetch covers every
  game at once, only followed live games add per-game `landing` requests.
- `/now` endpoints are never used — compute dates locally from the
  NTP-synced clock (they 307-redirect, doubling TLS round trips).
- Responses are cached and deduplicated; a byte-identical response does not
  re-publish a snapshot or re-render.
- `landing` (11 KB) — not `boxscore` (13.5 KB) or `play-by-play` (146 KB) —
  is the in-progress poll; it carries clock, period, score, shots, and the
  per-period scoring summary.
- The week `/v1/schedule/{date}` fetch (85 KB) backs the schedule cache for
  upcoming-game countdowns and refreshes at a slow cadence (e.g. hourly /
  on day rollover), not per poll tick.
- On repeated failures, back off exponentially (cap 5 min) and surface a
  staleness indicator rather than clearing displayed data.
- One TLS connection at a time, reused within a poll cycle; the feed session
  closes before the OTA updater runs (template rule, now applies to every
  fetch).

## Consequences

- Worst case (one followed game in `CRIT`): ~4 day-fetches + 4 landing
  fetches/min — modest for a CDN-fronted service and under the 30 s budget.
- No request lands faster than the CDN can refresh (14 s), so we never pay
  TLS overhead for stale bytes.

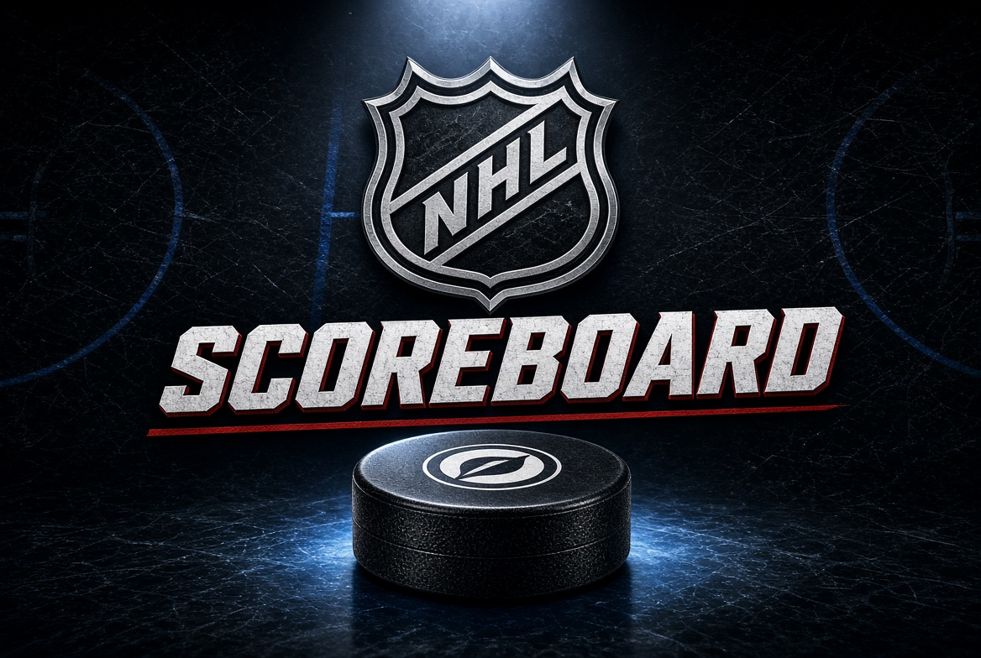
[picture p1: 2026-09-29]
src/sports/nhl/assets/nhlscoreboard.png

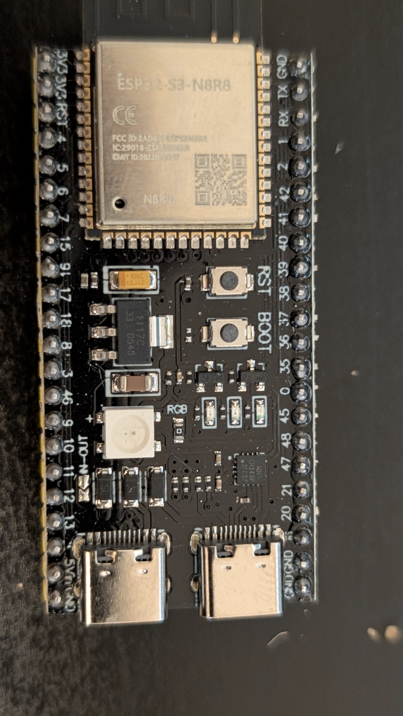
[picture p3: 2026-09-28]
docs/esp32s1-devkit1.jpg

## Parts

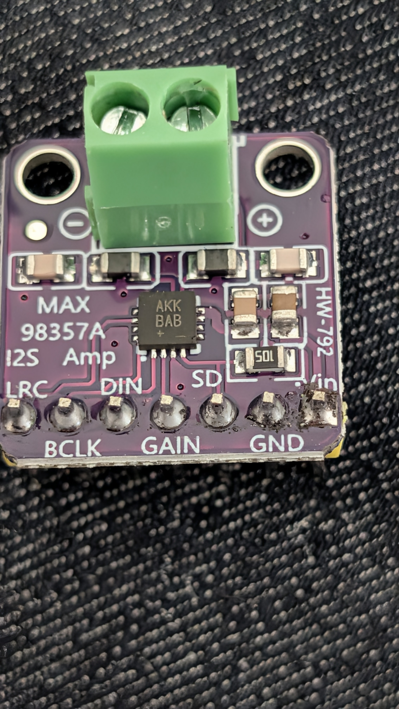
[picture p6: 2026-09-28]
docs/components/audioamp.jpg

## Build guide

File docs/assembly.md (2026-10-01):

# NHLScoreboard — Assembly & Wiring Guide

Everything needed to wire the scoreboard end to end. The pin plan and its
rationale live in [`hardware.md`](hardware.md); this document is the
build-side companion: parts, wiring tables, the rendered diagram, assembly
order, and the first-boot checklist. Firmware **v3.44** drives the
backplane-PCB pin map used here (TFT and guest penalty LEDs moved — see
`hardware.md`).

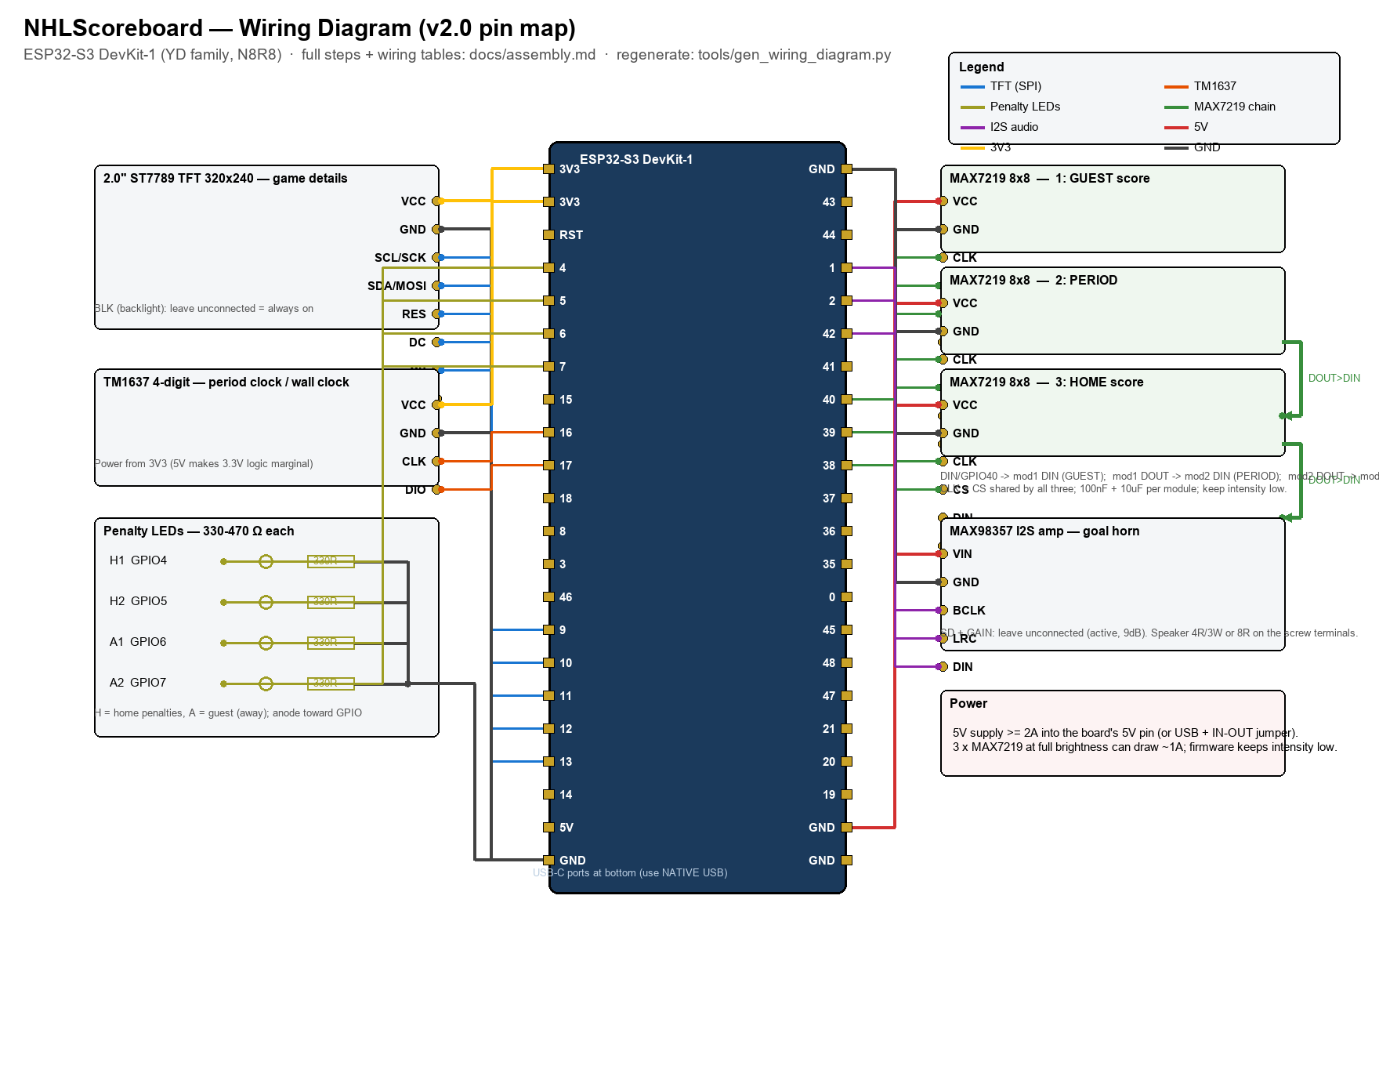
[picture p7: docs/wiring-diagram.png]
Wiring diagram


*(Diagram regenerated by `tools/gen_wiring_diagram.py` whenever pins
change — edit the script, not the PNG.)*

## Parts list

| Qty | Part | Role | Notes |
|---|---|---|---|
| 1 | ESP32-S3 DevKit-1 (N8R8) | controller | 8 MB flash, octal PSRAM; native USB-C port used for power/flash/serial |
| 1 | 2.0" ST7789V TFT, 240×320, SPI | game details screen | 7-pin module (VCC GND SCL SDA RES DC CS BLK) |
| 3 | MAX7219 8×8 LED matrix module | away score, home score, period | generic red 4-board strips split into single modules; daisy-chained |
| 1 | TM1637 4-digit 7-segment module | period clock / wall clock | 4 pins: VCC GND CLK DIO |
| 1 | MAX98357A I2S amp breakout | goal-horn audio | plus a 4 Ω/3 W (or 8 Ω) speaker |
| 4 | LED + 330–470 Ω resistor | penalty indicators | 2 home, 2 guest; 3 mm or 5 mm, any color |
| — | hookup wire, headers, perfboard | assembly | 22–24 AWG for power runs |

Power: a **5 V ≥ 2 A** supply feeding the board's 5V pin (or a strong USB
supply with the board's `IN-OUT` jumper closed). Three MAX7219 modules at
full brightness alone can draw ~1 A; the firmware keeps intensity low, but
size for the worst case.

## Wiring tables

Physical positions refer to the header map in `hardware.md` (counting from
the end nearest the RST button / top of the board photo).

### TFT — game details (left header)

| TFT pin | Goes to | GPIO | Phys. pos |
|---|---|---|---|
| VCC | 3V3 | — | L1/L2 |
| GND | GND | — | L22 |
| SCL/SCK | TFT SCK | 8 | L12 |
| SDA/MOSI | TFT MOSI | 3 | L13 |
| RES | TFT RESET | 46 | L14 |
| DC | TFT DC | 9 | L15 |
| CS | TFT CS | 10 | L16 |
| BLK | *(leave unconnected — backlight always on)* | — | — |

### TM1637 — period clock / wall clock (left header)

| TM1637 pin | Goes to | GPIO | Phys. pos |
|---|---|---|---|
| VCC | **3V3** (not 5 V — keeps logic levels matched) | — | L1/L2 |
| GND | GND | — | L22 |
| CLK | TM1637 CLK | 16 | L9 |
| DIO | TM1637 DIO | 17 | L10 |

### Penalty LEDs (left header)

GPIO → LED anode → resistor → GND, one per LED:

| LED | GPIO | Phys. pos | Resistor |
|---|---|---|---|
| Home penalty 1 | 4 | L4 | 330–470 Ω |
| Home penalty 2 | 5 | L5 | 330–470 Ω |
| Guest penalty 1 | 11 | L17 | 330–470 Ω |
| Guest penalty 2 | 12 | L18 | 330–470 Ω |

### MAX7219 chain — scores + period (right header)

| MAX7219 pin | Goes to | GPIO | Phys. pos |
|---|---|---|---|
| VCC (all 3) | 5V | — | L21 |
| GND (all 3) | GND | — | R1 |
| CLK (all 3, shared) | MAX7219 CLK | 39 | R9 |
| CS/LOAD (all 3, shared) | MAX7219 CS | 38 | R10 |
| DIN (**module 1 only**) | MAX7219 DIN | 40 | R8 |
| DOUT module 1 → | DIN module 2 | — | jumper |
| DOUT module 2 → | DIN module 3 | — | jumper |

Module order in the chain is **1 = guest score, 2 = period, 3 = home
score** (the shared-load shift order is handled in the driver). Add
100 nF + 10 µF decoupling per module.

### MAX98357A — goal horn (right header)

| Amp pin | Goes to | GPIO | Phys. pos |
|---|---|---|---|
| VIN | 5V | — | L21 |
| GND | GND | — | R1 |
| BCLK | I2S BCLK | 1 | R4 |
| LRC | I2S LRC/WS | 2 | R5 |
| DIN | I2S data | 42 | R6 |
| SD, GAIN | *(leave unconnected — active, 9 dB gain)* | — | — |

Speaker lands on the amp's screw terminals (4 Ω/3 W or 8 Ω).

### Power/ground summary

| Rail | Sources on board | Consumers |
|---|---|---|
| 3V3 | L1, L2 | TFT VCC, TM1637 VCC |
| 5V | L21 | 3× MAX7219 VCC, MAX98357 VIN |
| GND | L22, R1, R21, R22 | **everything** — one common ground |

## Assembly order

1. **Flash first, wire second.** With the bare board on USB, flash v2.0
   (`pio run -e esp32-s3-devkitc-1 -t upload --upload-port COM15`) and
   confirm the boot splash and the `NHL_SCOREBOARD` setup AP appear — a
   known-good controller before adding wiring.
2. Unplug. Mount the board and modules (perfboard/standoffs), keeping the
   matrix chain and amp away from the TFT ribbon.
3. **Power rails first**: 5 V and 3 V3 distribution, then a solid common
   ground tying every module back to the board.
4. TFT (7 wires, left header 15–19 + rails).
5. TM1637 (4 wires, left 9–10 + rails — 3V3!).
6. Penalty LEDs + resistors (home left 4–5, guest left 17–18).
7. MAX7219 modules: mount in order, wire the shared CLK/CS, feed DIN of
   module 1 from GPIO 40, then jumper DOUT→DIN between modules.
8. MAX98357 + speaker (right 4–6 + rails).
9. Double-check every row of the tables against the diagram before
   powering up.

## First-boot checklist

1. Splash shows the NHL logo + `v2.0`, then the setup screen with QR.
2. Join `NHL_SCOREBOARD`, configure Wi-Fi + your three teams in the
   portal, save — board reboots into waiting mode.
3. Waiting mode: TFT rotates upcoming-game card → league scores → news;
   **TM1637 shows the wall clock**; matrices show the idle clock (if
   enabled in the portal).
4. When a preferred team plays: live screen (logos, score, period,
   clock, SOG, penalties) within a minute of puck drop; **matrices show
   the scores, penalty LEDs light during power plays, TM1637 shows the
   period clock** (colon lit while play runs).
5. To watch the display bindings on serial (nothing to trust, just to
   see): build with `-DSB_DEBUG=1` and watch the `[BIND]` lines — one per
   5 s poll listing every value handed to the display drivers.

## Troubleshooting

- **Blank TFT**: check BLK isn't tied low, and that SCL/SDA didn't swap
  (GPIO 8 = SCK, GPIO 3 = MOSI on the PCB-rev map).
- **Garbled/one dead matrix**: the chain is positional — module 1 must be
  the one receiving GPIO 40 DIN; DOUT→DIN jumpers seat fully.
- **Dim or dead TM1637**: it's on 3V3 by design; on 5 V its inputs may
  miss 3.3 V logic highs.
- **No goal horn**: audio playback HAL is not implemented yet (the amp is
  wired for the day it lands — see `hardware.md` driver notes).
- **Everything dead at once**: measure 5 V at the board and at the far
  MAX7219; a starved rail browns out the matrices first.
- **First matrix works, downstream matrices dark**: measure the 5 V rail
  under load (during the display test's all-on phase — worst case ~1 A).
  A supply that sags browns out the modules further down the power bus
  while the one nearest the feed keeps running; it looks exactly like a
  broken DOUT→DIN chain link but isn't. (Seen in the field: fine on a
  boosted 5 V supply, modules 2–3 dark on a weaker one.)

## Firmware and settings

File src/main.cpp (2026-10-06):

// ============================================================================
// Generic scoreboard app shell.
// ============================================================================
// This file is sport-agnostic: it owns the boot sequence (splash hold,
// firmware-update screen, boot status page), network bring-up, and the
// one-shot NTP sync, then hands every loop pass to the sport implementation
// through the contract in common/app/sport_api.h. Which sport is compiled in
// is decided by platformio.ini (build_src_filter + include path pointing at
// src/sports/<sport>).

#include <Arduino.h>
#include <time.h>

#include "config.h"
#include "common/app/sport_api.h"
#include "common/comms/network_service.h"
#include "common/ui/boot_status.h"
#include "common/ui/ota_screen.h"

void setup() {
  Serial.begin(SERIAL_BAUD_RATE);

  // Sport bring-up FIRST: hardware init with the sport's pins, boot
  // tests, and the boot splash (its logo artwork belongs to the sport).
  // The splash paints within moments of power-on — nothing in front of
  // it, not even the USB CDC grace period below. In bare-metal mode
  // (bench test) this is also the LAST shell step — no network, no boot
  // UI; the sport's tick owns the display from the first loop pass.
  sport::setup();

  if (!sport::skipBootUi()) {
    // No blocking hold here: network services start immediately and connect
    // behind the logo. loop() enforces the minimum splash time instead, so
    // a fast Wi-Fi handshake can't cut the logo short.
    NetworkBranding branding = sport::branding();
    size_t teamOptionCount = 0;
    startNetworkServices(branding, sport::teamOptions(teamOptionCount),
                         teamOptionCount, sport::defaultPreferredTeams());
    startNetworkTask();
    sport::startDataTask();  // core-0 feed fetches
  }

  // Native USB CDC enumeration grace period — placed AFTER the splash and
  // network start (it used to sit first and delayed both by up to 3 s);
  // now it only guards the boot banner below. UART builds skip it
  // instantly (Serial is ready immediately there).
  uint32_t start = millis();
  while (!Serial && (millis() - start < 3000)) {
    delay(10);
  }

  // Boot banner — visible over Serial whenever SB_DEBUG=1 so a freshly
  // uploaded firmware can be confirmed at a glance.
  Serial.println();
  Serial.printf("[BOOT] FW=%s build=%s %s\n",
                FIRMWARE_VERSION, __DATE__, __TIME__);
  Serial.printf("[BOOT] heap_free=%u heap_min=%u\n",
                (unsigned)ESP.getFreeHeap(),
                (unsigned)ESP.getMinFreeHeap());
}

void loop() {
  if (sport::skipBootUi()) {
    SportTickContext ctx = {millis(), false, false};
    sport::tick(ctx);
    return;
  }

  // Boot sequence: (1) the logo splash holds BOOT_SPLASH_HOLD_MS while
  // the network task connects Wi-Fi behind it — a handshake still in
  // flight at the end of the window EXTENDS the splash (capped by
  // BOOT_SPLASH_CONNECT_MAX_MS, which matches the network service's own
  // connect budget) so the next screen shows the outcome, never a
  // half-state; (2) an in-progress firmware update owns the screen
  // whenever it runs; (3) once the connection is made, the status/setup
  // page shows for BOOT_SETUP_PAGE_MS; (4) if the connection cannot be
  // made, the AP provisioning page ("connect to the scoreboard") shows
  // instead and holds until the portal establishes the connection — then
  // the status page runs its window. The sport UI owns every frame after
  // that; network/update/game-data work runs on core 0 throughout.
  uint32_t bootNow = millis();
  if (bootNow < BOOT_SPLASH_HOLD_MS) {
    return;
  }
  if (handleOtaUpdateScreen()) {
    return;
  }
  // Anchor the setup page to the moment the network actually came up, so
  // a slow handshake eats into the splash instead of the page.
  static uint32_t onlineSinceMs = 0;
  if (onlineSinceMs == 0 && isOnline()) {
    onlineSinceMs = bootNow;
  }
  if (!isProvisioning()) {
    if (onlineSinceMs == 0 && bootNow < BOOT_SPLASH_CONNECT_MAX_MS) {
      return;  // still connecting: the splash keeps covering the boot
    }
    if (onlineSinceMs != 0 &&
        bootNow - onlineSinceMs < BOOT_SETUP_PAGE_MS) {
      renderBootStatusPage(sport::name());
      return;
    }
  }

  handleNetworkDisplay();

  // One-shot NTP sync once the network is up. The display timezone is a
  // portal setting (NVS "tz"); the factory default in src/config.h only
  // covers the very first boot, and a mid-session portal change applies
  // itself via setenv/tzset in the network service.
  static bool timeSyncRequested = false;
  if (!timeSyncRequested && isOnline()) {
    configTzTime(getTzString(), "pool.ntp.org", "time.nist.gov");
    timeSyncRequested = true;
    DBG_PRINTF("[TIME] NTP sync requested; timezone=%s\n", getTzString());
  }

  SportTickContext ctx = {millis(), isOnline(), isProvisioning()};
  sport::tick(ctx);
}

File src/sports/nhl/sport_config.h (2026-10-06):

#pragma once

#include <Arduino.h>   // uint32_t & friends — config headers are self-sufficient

// ============================================================================
// NHL scoreboard — sport + device profile.
// ============================================================================
// This file (named sport_config.h in every sport folder) is what the generic
// framework in src/common/ composes in via the include path each PlatformIO
// env sets up. It carries everything that changes between sports AND between
// physical builds: display pins/geometry, branding strings, feed poll
// cadences, and UI layout constants.
//
// Starting a new sport from this template: copy src/sports/nhl to
// src/sports/<sport>, edit this file, and point the env's -I flag and
// build_src_filter at the new folder (see README "new sport" checklist).

// ---- 2.0-inch ST7789V TFT (320x240, software SPI) --------------------------
// The 5-arg software-SPI constructor is deliberate: on ESP32-S3 the 3-arg
// hardware-SPI variant binds SPI.begin() to the variant's default VSPI pins
// instead of these, leaving a blank screen. See main.cpp's display comment.
// Backplane-PCB rev map (v3.44): SCL=8, SDA=3, CS=10, DC=9, RES=46. GPIO 3
// and 46 are strapping pins — fine as outputs after boot (46's reset-time
// state only gates ROM log output), but the TFT must not drive them during
// power-up (its SDA/RES lines are inputs, so it can't).
static const int TFT_SCLK_PIN = 8;
static const int TFT_MOSI_PIN = 3;
static const int TFT_CS_PIN = 10;
static const int TFT_DC_PIN = 9;
static const int TFT_RESET_PIN = 46;
static const int TFT_BACKLIGHT_PIN = -1;
static const int TFT_NATIVE_WIDTH = 240;
static const int TFT_NATIVE_HEIGHT = 320;

// ---- MAX7219 8x8 LED Matrix displays (daisy chain: away, home, period) -----
// Target physical map (docs/hardware.md): right header pos 8-10. The
// led_matrix HAL currently drives the first two modules; the period module
// joins when the HAL extends to three devices.
static const int MAX7219_DIN_PIN = 40;
static const int MAX7219_CLK_PIN = 39;
static const int MAX7219_CS_PIN = 38;

// ---- TM1637 4-digit 7-segment (period/game clock; wall clock when idle) ----
// Target physical map: left header pos 9-10.
static const int TM1637_CLK_PIN = 16;
static const int TM1637_DIO_PIN = 17;
static const int TM1637_BRIGHTNESS = 3;   // 0..7

// ---- Penalty LEDs (home P1/P2, guest P1/P2) --------------------------------
// Backplane-PCB rev map (v3.44): home 4/5, guest 11/12 (guest moved off
// 6/7 for the new routing). count_leds drives a 3/2/2 pin grouping;
// penalties need 2+2, so the unused slots point at free pins. FILL_A must
// stay off GPIO 8 (now the TFT SCL — initCountLeds would claim it) and sits
// on 13, the freed old TFT SCK.
static const int PENALTY_HOME1_PIN = 4;
static const int PENALTY_HOME2_PIN = 5;
static const int PENALTY_AWAY1_PIN = 11;
static const int PENALTY_AWAY2_PIN = 12;
static const int PENALTY_FILL_A  = 13;    // group A 3rd slot (never lit)
static const int PENALTY_FILL_B1 = 15;   // group C slots (never lit)
static const int PENALTY_FILL_B2 = 18;

// ---- MAX98357 I2S audio amp (goal horn) ------------------------------------
// Target physical map: right header pos 4-6.
static const int I2S_BCLK_PIN = 1;
static const int I2S_LRC_PIN = 2;
static const int I2S_DIN_PIN = 42;

// ---- Branding (AP network name, hostname, portal title) ---------------------
static const char* NETWORK_AP_SSID = "NHL_SCOREBOARD";
static const char* NETWORK_HOSTNAME = "nhl-scoreboard";

// ---- UI theme (RGB565) -------------------------------------------------------
// Shared by the sport renderer AND the generic boot/OTA screens (they include
// config.h). A new sport overrides these to re-skin the whole UI.
static const uint16_t COLOR_BG = 0x0821;        // Dark slate
static const uint16_t COLOR_CARD = 0x18A5;      // Card background
static const uint16_t COLOR_GOLD = 0xFD20;      // Gold accent
static const uint16_t COLOR_YELLOW = 0xFFE0;    // Count / runner yellow
static const uint16_t COLOR_MUTED = 0x7BEF;     // Gray text/icon
static const uint16_t COLOR_LED_RED = 0xF800;   // Bright red for LED dot display
static const uint16_t COLOR_LED_OFF = 0x2100;   // Dark unlit LED dot background
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

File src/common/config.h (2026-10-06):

#pragma once

#include <Arduino.h>   // uint32_t & friends — config headers are self-sufficient

// ============================================================================
// Framework defaults — shared by every scoreboard built on this template.
// Nothing in here knows about a specific sport, feed, or display layout;
// sport/pin/branding constants live in the selected sport's sport_config.h.
// ============================================================================

// Serial
static const uint32_t SERIAL_BAUD_RATE = 115200;

// Compile-time debug log gate. Set to 0 in production builds to drop the
// per-tick [DISPLAY]/[API CALL] printf noise (a Serial.printf at 115200 baud
// stalls the loop ~25 ms — measurable against the 5s poll cadence). Enable by
// uncommenting or passing -DSB_DEBUG=1 in build_flags during development.
#ifndef SB_DEBUG
#define SB_DEBUG 0   // production default; pass -DSB_DEBUG=1 in build_flags to diagnose
#endif
#if SB_DEBUG
#define DBG_PRINTF(fmt, ...) Serial.printf(fmt, ##__VA_ARGS__)
#else
#define DBG_PRINTF(fmt, ...) do {} while (0)
#endif

// Boot sequence: the scoreboard logo splash holds the screen for at least
// BOOT_SPLASH_HOLD_MS while Wi-Fi connects behind it. A handshake still in
// flight at the end of that window EXTENDS the splash up to
// BOOT_SPLASH_CONNECT_MAX_MS (sized to the network service's own connect
// budget), so the screen that follows shows the outcome: once the
// connection is made, the status/setup page shows for BOOT_SETUP_PAGE_MS;
// if it cannot be made, the AP provisioning page ("connect to the
// scoreboard") shows instead and holds until the portal establishes the
// connection. The sport UI takes over after that.
static const uint32_t BOOT_SPLASH_HOLD_MS = 5000;
static const uint32_t BOOT_SPLASH_CONNECT_MAX_MS = 30000;
static const uint32_t BOOT_SETUP_PAGE_MS = 6000;

// Network portal login + dev-flashing password (device-level, not sport).
static const char* NETWORK_AP_PASSWORD = "score1234";
static const char* NETWORK_PORTAL_PASSWORD = "score";
// Network (Arduino) OTA: used by `pio run -t upload --upload-port <ip>` during development.
static const char* NETWORK_OTA_PASSWORD = "score1234";
// Connectivity probe: any HTTP response from this anchor means the uplink works.
static const char* NETWORK_PROBE_ANCHOR_URL = "http://connectivitycheck.gstatic.com/generate_204";
static const uint32_t NETWORK_CONNECT_AND_PROBE_TIMEOUT_MS = 30000; // assoc + internet probe budget
static const uint32_t NETWORK_PROBE_INTERVAL_MS = 5000;
static const uint32_t NETWORK_RECONNECT_GRACE_MS = 15000; // sustained drop before re-provisioning
static const uint32_t NETWORK_RECONNECT_RETRY_MS = 5000;
static const uint32_t NETWORK_DEBUG_INTERVAL_MS = 10000;
static const uint32_t NETWORK_SETUP_SCREEN_MS = 0;         // online screen no longer drawn; release scoreboard immediately
static const uint32_t NETWORK_SCAN_REFRESH_MS = 30000;    // portal scan-list cache age
static const uint32_t NETWORK_PROVISIONING_RETRY_MS = 60000; // retry saved Wi-Fi after this long in AP mode
// While anyone is using the setup portal (any HTTP request refreshes this
// window), feed fetching pauses entirely so the portal loads fast even on
// this device's marginal Wi-Fi.
static const uint32_t PORTAL_ACTIVITY_WINDOW_MS = 120000;
// Formerly held the (now removed) Wi-Fi connecting screen up at boot; the
// boot logo covers that role. Kept at zero so nothing delays going online.
static const uint32_t NETWORK_FIRST_CONNECT_MIN_MS = 0;

// Firmware self-update pacing (endpoints live in src/config.h — they are
// repo identity, not framework policy).
static const uint32_t OTA_FIRST_CHECK_AFTER_ONLINE_MS = 5000; // runs behind the boot screens; needs the pristine boot heap
static const uint32_t OTA_BOOT_GATE_TIMEOUT_MS = 25000; // feeds must not starve behind failed TLS attempts
// No periodic recheck: the automatic OTA check is boot-only (one session
// per power cycle, before any feed fetch); the portal can still trigger
// one on demand.
static const uint32_t OTA_DOWNLOAD_STALL_MS = 30000;  // abort a download with no progress

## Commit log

2026-09-21 Initial commit: MLBScoreboard v2.60 template as NHLScoreboard starting point
    Copy of ubiconet/mlb_scoreboard at v2.60 (post template refactor) with the
    repo identity rewired for the NHL project:
    - OTA manifest/latest-bin URLs (src/config.h) -> ubiconet/NHLScoreboard,
    binary name nhl_scoreboard_latest.bin
    - tools/release_deploy.py RAW_BASE/LATEST_FILE + archive/commit naming
    - FIRMWARE_VERSION reset to v1.0 (fresh version chain for a new project)
    - README/AGENTS retitled for the NHL port
    The sport layer (src/sports/mlb) is intentionally untouched: this builds
    the MLB scoreboard unchanged and is the baseline for the NHL port per the
    'Starting a new sport' checklist in README.md. Framework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
    [partitions.csv]
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2026-09-29 News page redesign + full-story scroll; drop NHL SCOREBOARD header bar (v3.7)
    - News story page: headline as large centered white text (sizes 5..2,
    auto-fit) filling the freed upper section; story details scroll
    through the whole description before the carousel advances (short
    descriptions fall back to the 10 s dwell); milli-pixel scroll
    accumulator keeps pacing exact at any loop cadence
    - Remove the 24 px NHL SCOREBOARD header bar from every waiting page;
    league/list pages reflow upward and gain a row each
    - Remove the NHL NEWS label and story counter from the news page
    - FIRMWARE_VERSION v3.6 -> v3.7
    [config.h, sport_config.h]
2026-09-29 Fix waiting-carousel freeze: logo scaler infinite loop + scroll resets (v3.9)
    Two bugs surfaced once the carousel first rendered an upcoming-game
    card (tomorrow-lookahead slate):
    - drawTeamLogoScaled computed step = 64/size, which is 0 for any size
    > 64 - the upcoming card draws 88 px logos, so the first card render
    spun row += 0 forever on the render core, freezing the whole device
    with the previous screen (the news story) still displayed. Replaced
    with destination-driven nearest-neighbor sampling that handles any
    size. The old 72 px hero card had the same latent bug.
    - Story slides now keep their scroll position when a schedule publish
    repaints the same slide; the scroll only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
    [config.h]
2026-09-29 Upcoming games span a full week; 8 s card dwell (v3.10)
    - New fetchNhlWeekSchedule: /v1/schedule/{date} returns the Mon-Sun
    week in one call (~85 KB raw); filtered to gameWeek[]{date, games[]
    {id, gameState, startTimeUTC, teams}}. Week-schedule parse carries
    the day-score's tail-truncation tolerance (kept fields precede the
    skipped media/odds bulk); requires all 7 days to accept.
    - Data task keeps a week cache refreshed at most every 6 h (future-day
    states never change; today's half of the upcoming doc always comes
    from the fresh 60 s day-score poll) with 15 min retry spacing. The
    upcoming-games doc now carries every game after today through
    Sunday, so per-team cards and the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
    [config.h, sport_config.h]
2026-09-29 Live game clock ticks between polls, freezes with the real clock (v3.11)
    The TM1637 + TFT header clock previously only refreshed on the 5 s
    landing poll, so it sat frozen between polls regardless of play. The
    renderer now keeps a local clock model: renderLiveGame re-syncs the
    basis from every poll's clockSec, and the new tickLiveClock() (called
    each loop pass) counts it down in real time while the game clock runs
    (clockRunning && !inIntermission) and freezes when it is stopped.
    Re-sync policy: while continuously running, a 2 s deadband keeps local
    continuity so fetch latency never stutters the display a second back
    and forth; any run/stop transition or drift beyond the deadband
    (period star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
    [config.h, nhl_app.cpp, nhl_renderer_linescore.cpp]
2026-09-29 Carousel: detailed card per upcoming game, interleaved with news (v3.12)
    - Drop the multi-game UPCOMING GAMES list slide; every upcoming game
    in the week look-ahead now renders as its own detailed card (logos,
    abbrevs, date/time, countdown, GAME X OF Y footer), chronological,
    up to 64 games
    - Cards and news stories interleave in the carousel - card, story,
    card, story - running the longer tail of whichever side has more
    entries; the around-the-league slide leads when games are on; the
    no-games diagnostic page shows only when there is nothing at all
    - Card selection no longer filters by preferred teams (the whole
    week's slate is shown); renderWaiting keeps its signature
    - FIRMWA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
    [config.h]
2026-09-29 Goal flash on the scoring side; horn only for favorite teams (v3.13)
    - A score increase between landing polls now draws that team's score
    box inverted (gold fill, dark digits) for 500 ms (NHL_SCORE_FLASH_MS)
    before the per-tick hook restores the normal box. The flash fires
    for either team; score corrections downward and game switches do
    not flash.
    - The goal horn previously fired for ANY goal in the followed game;
    it now plays only when the scoring team is one of the user's
    preferred teams, and still respects the portal sound toggle.
    - FIRMWARE_VERSION v3.12 -> v3.13
    [config.h, nhl_app.cpp, nhl_renderer_linescore.cpp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]
2026-09-29 Live screen: SOG panels up top, penalties or league scores below (v3.14)
    - Top half: shots-on-goal panels - HOME left, GUEST right - each with
    the team logo, abbreviation and big shot count. The TFT no longer
    duplicates the score (matrices own it); the goal flash now inverts
    the scoring team's SOG panel for 500 ms instead of the old score box
    - Bottom half: while penalties are active, one row per penalty with
    team, sweater number + last name and remaining penalty time
    (committedByPlayer lastName/sweaterNumber added to the landing
    filter, snapshot struct and mapping); at even strength the half
    shows the scores of the league's in-progress games (followed game
    excluded), or a qu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
    [config.h, nhl_renderer_linescore.cpp]
2026-09-29 OTA: boot-only update checks (v3.17)
    The periodic mid-session recheck was the unreliable path: post-feed
    heap fragmentation can't fund mbedTLS's 2x16 KB handshake buffers
    (WiFiClientSecure::setBufferSizes doesn't exist on Arduino-ESP32
    2.0.x — the sizes are baked into the prebuilt library), and the AP
    refuses fresh TLS handshakes after the session's first connections.
    Per product decision the automatic check now runs exactly once per
    boot — in the pristine-heap window before any feed fetch, as the
    session's first TLS connection, over the one reused session — which
    is the configuration that has historically delivered updates. The
    portal's manual check-now remains available.
    - FIRMWARE_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
    [config.h]
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2026-09-29 Fix smeared team-logo PNGs; switch rasterizer to resvg (v3.20)
    The svglib+reportlab rasterizer dragged the right side of ~19 of the
    32 crest renders (ANA CAR CBJ CGY CHI COL DET EDM FLA MIN NJD NYI OTT
    PIT SEA SJS UTA VAN VGK among the worst - the SVGs were always
    clean). Vendored resvg v0.47.0 at tools/bin/resvg.exe and rewrote
    tools/gen_team_logo_pngs.py around it (native alpha, 4x zoom, same
    crop/fit/center rules). Regenerated all 32 PNGs, the contact sheet,
    and team_logos.h.
    - FIRMWARE_VERSION v3.19 -> v3.20
    [config.h, gen_team_logo_pngs.py]
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2026-09-29 Portal: Manual Mode link becomes a button; stale OTA hint fixed (v3.23)
    The settings screen's Manual Mode entry was a plain gold text link;
    now it's a full-width gold button matching the Display Test / Audio
    Test buttons on the same page. Also corrects the firmware-update hint,
    which still claimed automatic checks run every 10 minutes - they are
    boot-only since v3.17.
    - FIRMWARE_VERSION v3.22 -> v3.23
    [config.h, network_service.cpp]
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2026-09-29 MAX7219: home score on the home matrix, guest on guest (v3.25)
    The driver's chain-role assumption had the module nearest the DIN
    feed as GUEST and the far end as HOME; the physical build is the
    opposite, so the scores (and the boot test's H/A letters) showed on
    the wrong modules. Swapped the role mapping in the HAL: chain
    position 1 (nearest DIN) = HOME, position 3 = GUEST; period stays on
    position 2 with its mounting rotation, and the ~50% dim module
    follows GUEST. Chain-diagnostic narration updated to match. The
    waiting-mode clock now puts the hour on the physical home module and
    minutes on guest.
    - FIRMWARE_VERSION v3.24 -> v3.25 (local; not published)
    [config.h, led_matrix.cpp]
2026-09-29 Live screen restack: logos top, labeled SHOTS row, penalties below (v3.26)
    New vertical layout per spec: each team's logo (84 px, HOME left /
    GUEST right) at the top of the TFT, a clearly labeled SHOTS row under
    each logo (muted label + big gold count), and the bottom section for
    active penalties (team, player number + last name, remaining time) or,
    at even strength, the league's live scores - now three rows to fit the
    stack. The goal flash inverts the scoring team's SHOTS box for 500 ms.
    - FIRMWARE_VERSION v3.25 -> v3.26 (local; not published)
    [config.h, nhl_renderer_linescore.cpp]
2026-09-29 Game clock sync: converge when behind the feed (v3.27)
    The anti-jitter deadband held the local estimate whenever |drift| was
    <= 2 s, which could pin a permanent 1-2 s lag when the display fell
    behind the landing feed. Now: snap to the polled clockSec whenever the
    display is behind (drift > 0, forward jumps only), and hold the local
    ticking estimate only while ahead by <= 2 s - that direction is just
    transport staleness, and snapping to it would stutter the clock
    backward every poll. Large drift and run/stop transitions still snap
    both ways, and the model re-anchors on every 5 s poll.
    - FIRMWARE_VERSION v3.26 -> v3.27 (local; not published)
    [config.h, nhl_renderer_linescore.cpp]
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2026-09-29 Period clock freezes on feed-detected stoppages (v3.31)
    The clock already pauses on the feed's running=false and during
    intermission, but the arena's running flag can lag a real stoppage -
    the board then ticked past a dead clock until a later poll snapped it
    back. Added feed-truth stop detection: a clock that claims to be
    running but reports the SAME value on consecutive ~5 s polls is
    stopped at the source, so the display (and the penalty countdowns
    riding it) freeze until the polled value moves again - i.e., until
    play actually restarts.
    - FIRMWARE_VERSION v3.30 -> v3.31 (local; not published)
    [config.h, nhl_renderer_linescore.cpp]
2026-09-30 Restore original matrix chain mapping; 25% dimmer matrices (v3.32)
    The v3.25 role swap guessed the physical chain direction wrong - the
    board showed home scores on the guest matrix and vice versa. Reverted
    to the original mapping: chain position 1 (nearest DIN) = guest,
    position 3 = home, period stays on position 2; the boot test puts H on
    the home module again. Matrix brightness reduced ~25%: intensity
    15 -> 11 on home/period and 7 -> 5 on the dimmer guest module (the
    waiting-mode clock keeps its near-minimum setting).
    - FIRMWARE_VERSION v3.31 -> v3.32
    [config.h, led_matrix.cpp]
2026-09-30 Live feed outage handling: landing backoff + stale continuation (v3.34)
    Observed live: the landing polls hit the flaky-TLS window (dead
    keep-alive socket -> fresh handshakes refused by the AP) and the board
    froze mid-period on its last snapshot while the game moved on.
    - Landing fetch failures now back off exponentially (5 s doubling to
    a 60 s cap, reset on success) instead of hammering fresh TLS
    handshakes every 5 s — the retry discipline that already fixed the
    schedule fetch (ADR-0002).
    - Renderer stale continuation: with no fresh snapshot for 90 s the
    frozen clock resumes ticking and penalties expire on their own
    (closer to truth than freezing mid-play) until data returns. Re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
    [config.h, nhl_renderer_linescore.cpp, sport_config.h]
2026-09-30 Penalty clocks freeze during intermissions (v3.35)
    During an intermission the landing feed's clock carries the break
    countdown, not period time; deriving game-elapsed from it burned
    penalty time during the pause (observed live in MTL-TOR: offsetting
    minors lingered through a long mid-P2 break). Penalty math now
    anchors to the last in-play clock reading — penalty clocks stop with
    play and resume with it, like real hockey.
    - FIRMWARE_VERSION v3.34 -> v3.35 (local; not published)
    [config.h]
2026-09-30 Intermission display + scoreboard-style SHOTS boxes (v3.36)
    Between periods (clock.inIntermission is a real intermission, not a
    commercial break): the clock shows the NEXT period already - its
    opening time (20:00 regulation, 5:00 OT) frozen until puck drop - the
    period matrix advances to the next number, and penalties are hidden
    (bottom half falls back to the league view, penalty LEDs dark). On
    resume the feed flips the flag with the new period at full clock and
    the display re-anchors in one poll.
    Also: each team's shots area is now an arena-stat-panel style box -
    2-px white rounded border, doubled-size white SHOTS label, big gold
    count; the goal flash fills it gold with dark text.
    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
    [config.h, nhl_renderer_linescore.cpp]
2026-09-30 Live screen: logos 20% smaller, clear gap above the SHOTS boxes (v3.37)
    Crests shrink 84 -> 67 px (columns re-centered on the same axis
    lines) and the shots boxes drop to y 88 with widened side padding,
    leaving a ~15 px gap between logo and box instead of the previous
    4 px jam; ~10 px below the box before the bottom section.
    - FIRMWARE_VERSION v3.36 -> v3.37 (local; not published)
    [config.h, nhl_renderer_linescore.cpp]
2026-09-30 Goal feedback: blink the new score on the matrix; shots box static (v3.39)
    The SHOTS boxes no longer change appearance on a goal - they render
    identically in every state. Instead, when a team scores its NEW score
    blinks on its score matrix: 3 flashes of ~250 ms on / 250 ms off,
    then back to the steady display (NHL_SCORE_BLINK_FLASHES /
    NHL_SCORE_BLINK_HALF_MS in sport_config.h). The blink runs from the
    per-tick hook on wall-clock time, both sides can blink at once, and
    score corrections downward never blink.
    - FIRMWARE_VERSION v3.38 -> v3.39 (local; not published)
    [config.h, nhl_renderer_linescore.cpp, sport_config.h]
2026-09-30 GAME OVER screen + 2-minute postgame grace (v3.41)
    When the followed game ends (FINAL/OFF/OVER) the bottom half shows
    GAME OVER centered in white below the shot counters for the grace
    window, which shortens from 5 to 2 minutes before the board returns
    to the waiting carousel. Penalty time refresh is suppressed while the
    GAME OVER view owns the bottom half. Includes the queued v3.39/v3.40
    changes: matrix score blink on goals (shots boxes static), white team
    abbreviations under the logos, shots box pushed lower.
    - FIRMWARE_VERSION v3.40 -> v3.41
    [config.h, nhl_renderer_linescore.cpp, sport_config.h]
2026-09-30 Smooth game-clock strategy; centered standings headers (v3.42)
    Clock: mid-run re-anchoring (the stutter) and stoppage flag-lag (the
    rewind) are gone. While running, the display ticks on wall time and is
    never re-anchored - transport staleness (polled value 0-3 s above the
    display) is absorbed, not corrected. Stoppage detection compares the
    polled value against the ticking display: when it stops dropping
    (drift turns positive), the display freezes within one poll, capping
    over-tick at 3 s. The displayed value never increases except a single
    deliberate correction when accumulated error exceeds 5 s; small leads
    persist and re-anchor for free at the next stoppage; resumes anchor to
    the lower of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
    [config.h, nhl_renderer_linescore.cpp]
2026-09-30 Shootout 'SO' on the period matrix; end-of-period/game buzzer (v3.43)
    - When periodType is SO the period module shows the letters SO (two
    3x5 glyphs in the two-digit slot layout) instead of a number.
    - New buzzer clip (synthesized arena klaxon, 1.8 s, tools/
    gen_buzzer_wav.py -> assets/buzzer.wav -> BUZZER_* in audio_clips.h)
    plays once when a period ends (first poll entering intermission)
    and when the game ends (FINAL/OFF/OVER edge), gated on the sound
    setting. Confirmed the goal blink already fires for EITHER team's
    score (home and guest paths are symmetric; only the horn is
    favorites-only by design).
    - FIRMWARE_VERSION v3.42 -> v3.43 (local; not published)
    [config.h, gen_buzzer_wav.py, led_matrix.cpp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]
2026-10-01 PCB-rev pin map, shorter boot splash, manual-mode end-of-period buzzer (v3.44-v3.46)
    - v3.44: backplane-PCB pin map — TFT SCK=8/MOSI=3/CS=10/DC=9/RST=46,
    guest penalty LEDs 11/12, PENALTY_FILL_A off GPIO 8 (now TFT SCL) to 13;
    docs (hardware/assembly/pcb/AGENTS) updated to match
    - v3.45: boot splash 16 s -> 11 s
    - v3.46: manual mode — at 0:00 the end-of-period buzzer sounds, ~3 s later
    the period advances and the clock reloads to the new 'period length'
    setting (stopped); manual page now syncs from the device once a second
    [config.h, network_service.cpp, nhl_app.cpp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]
2026-10-02 Fix smeared shot counts: erase SOG number region + fixed digit cells (v3.49)
    drawTeamColumn drew the count with transparent glyphs and no erase, so
    every value change layered old digit remnants over the new number.
    Wipe the interior below the SHOTS label first (same pattern as the
    header clock and penalty timers), then draw each digit centered in a
    30-px cell so multi-digit counts space evenly.
    [config.h, nhl_renderer_linescore.cpp]
2026-10-06 Add per-period linescore, three stars, and reworked shots row (v3.51)
    [config.h, nhl_renderer_linescore.cpp, sport_config.h]
2026-10-06 Rework boot sequence: instant splash, connect-anchored setup page, AP fallback (v3.52)
    [config.h, main.cpp, nhl_app.cpp]
2026-10-09 Fix standings: widen division-name buffer so all 8 teams per division parse (v3.53)
    [config.h]
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2026-10-17 Add low-battery power gate: warning screen + deep sleep; v3.59
    - common/app/power_monitor: power-on battery check via optional divider
    on GPIO 14 (ADC2_CH3, left header pos 20) + NVS boot journal that
    detects brownout boot storms when no divider is wired
    - common/ui/low_battery_screen: flashing battery icon + voltage warning
    - New board version V1.1 (portal-selectable, inherits the V1.0 pin map)
    enables the divider check per board; V0.1/V1.0 boards run unchanged —
    the sense pin is never read and only the boot-storm backstop applies
    - Deep sleep ends the on/off cycling; on V1.1 boards silent 15-min
    rechecks resume automatically once the charger is attached
    - Divider wiring diagram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
2026-10-20 Board version moves to diagnostics; blank SSID disconnects Wi-Fi; v3.68
    - The Board Version selector now lives on the /diag page with its own
    save form (posts to /save; a board-only save never touches the Wi-Fi
    settings and links back to diagnostics)
    - Clearing the Wi-Fi network name on the setup page and saving now
    FORGETS the network: credentials are removed from NVS, the station
    link drops, and the board returns to its setup access point (the
    on-screen instructions carry the network name and portal address);
    the ssid field is no longer required, and the first-configuration
    'network name is required' check still guards a truly empty setup
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2026-10-24 Remove reboot battery shutdown backstop
    Only the V1.1+ battery divider reading can trigger low-battery sleep.
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2026-10-25 MAX7219: kill the power-on matrix flash — initLedMatrix now drives DIN/CLK/CS low and flushes NOOP words before the first CS rising edge (noise that clocked garbage while the bus floated gets discard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
2026-10-25 Goal celebration: preferred-team goals (and demo goals) now flash the two score matrices alternating regular/reverse-video — scoring side inverts first, 250 ms half-phases — while the four penalty LE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
2026-10-25 Deploy: optional website mirror — after the GitHub publish, _publish_website() copies the release (app + factory + bootloader/partitions/boot_app0 bins, manifest.json) into SITE_ROOT/firmware/nhl/ fo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
2026-10-25 Deploy: website mirror now generates browsable index.html pages — /firmware/ (one row per board with published binaries, ready for future miniboard repos) and /firmware/nhl/ (latest release pinned wi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
2026-10-25 MAX7219: fix the v3.81 regression — random garble at power-on instead of the occasional flash. Cause: v3.81 moved the full register init to the top of boot, but the ESP32 executes while the 5V boost 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
2026-10-25 Deploy: netlify publish fixes — resolve netlify.cmd explicitly on Windows (shutil.which can return the extensionless sh shim that subprocess can't launch), avoid copytree dirs_exist_ok (older system 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
2026-10-25 Deploy: Netlify publish prefers GitHub — _publish_netlify() probes the site's repo link (netlify api getSite) and, once the miniboards site is connected to ubiconet/scoreboard-site in the Netlify UI,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
2026-10-26 Goal flash: only the scoring team's matrix flashes, now inverted (reverse video) instead of blanking
    Every score increase flashes that team's NEW score on its own matrix alone:
    normal 250 ms / inverted 250 ms x3 (was score/dark blanking). The preferred-team
    horn celebration no longer alternates BOTH matrices — the scoring side alone
    inverts while the other holds its steady score (penalty-LED strobe unchanged).
    setMax7219Shootout gains invert flags so shootout frames invert the scoring
    side too (previously the celebration flashed shootout scores dark). v3.87.
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2026-10-26 Period clock reads 00:00 when the period or game ends
    syncClockModel zeroed the timer only at intermission via the next period's
    opening clock (20:00/5:00 preview); now both intermission and FINAL/OFF/OVER
    snap the TM1637 clock to 00:00 — the feed can stop the clock above zero when
    the winning goal comes with time remaining, which froze the timer mid-count.
    Puck drop re-anchors past CLOCK_MAX_LEAD so 20:00 snaps in cleanly. v3.88.
2026-10-26 Portal update-check errors: name sports-miniboards.com, not GitHub
    The check-now failure/download-failed portal strings still blamed 'this
    network may block GitHub' from the pre-v3.86 era — the device polls
    sports-miniboards.com, so the message pointed users at the wrong host.
    Messages now name the real endpoint and note checks are most reliable just
    after a power-cycle (the TLS handshake needs the pristine boot heap);
    stale GitHub comments in ota_update.h / nhl_data_task.cpp updated to match.
2026-10-26 OTA fix: manifest outgrew the updater's 512-byte buffer — every check silently failed
    readExactBody() refuses any body larger than its buffer, and the manifest grew
    to ~775 B (Netlify) / ~915 B (GitHub raw) when the flasher-tool fields
    (factory/bootloader/partitions/boot_app0 pairs) were added — so no device
    could see any release since; checks failed in the boot window and the board
    kept running its old firmware. The staging buffer is now a 2 KB static
    (sManifestBuf), sized with headroom and off the data task's tight stack.
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
